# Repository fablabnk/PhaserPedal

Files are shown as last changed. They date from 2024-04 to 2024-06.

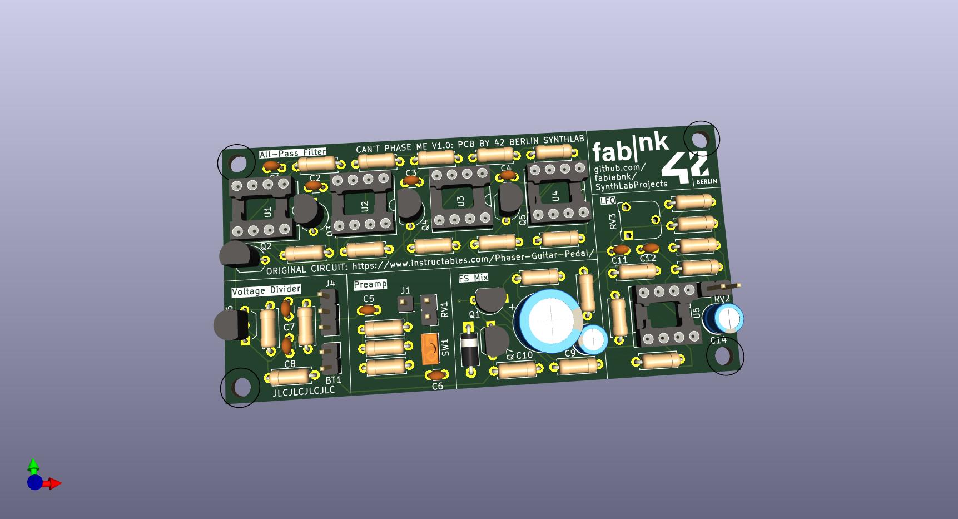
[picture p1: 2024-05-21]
3dPedal.jpg

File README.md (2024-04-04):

This was a project to build a [Phaser Guitar Pedal from Instructables](https://www.instructables.com/Phaser-Guitar-Pedal/). 

As we attempted the project, we found that the build steps in the photos were incomplete, so it is actually impossible to place all components and make all the solder connections on the protoboard in the same way they did.

Our solution was to attempt to rework a new layout directly from the schematic in KiCad, partly as a learning experience in how to use KiCad at all. This involved:

- recreating the schematic in the schematic editor
- creating a board template in the pcb editor and placing components as similarly as possible to the original project
- routing the rats nest
- using the routings as a template for soldering

- some connections are done with solder bridges, some with wires - the wires are the traces - but how did we do solder bridges again?

The current state of the project is that the circuit doesn't work and we're not sure why. One wire got disconnected so this could help.

A possible next step could be to manufacture a PCB, but we have no guarantee that we routed it correctly or that the project even works in the first place.

So it would be better to go back to first principles to understand the concepts in the circuit

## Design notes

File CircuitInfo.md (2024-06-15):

# V1.1

Aims:
- get it working with original BOM

Tasks:
- DONE: get schematic to pass ERC check
- mount to the case using tape etc. Case spec: HA29830PSLA: 120x95x34mm
- Audio In, Audio Out, 2 x pots, Footswitch and 9V battery will all be point-to-point wired
- DONE: use DPDT footswitch instead of SPST: it's the only footswitch we have
    - when closed, clean signal only makes it to output. when open, phased signal allowed through to be mixed with clean signal
    - we will wire only one pole and one throw of the DPDT, the other will remain disconnected
    - we presume pin 2 is connected to pin 1 when switch is in up position (clean) so will wire our phaser to pin 3 (wet)
- optimise component placement
- does jack wiring make sense? tip to ground etc?
- route it using ground plane - does power plane make sense?

# Lasercut Layout Test Notes

inline transistor footprints would have been fine!
we have no:     
    - 43K resistor:  33K + 10K
    - 3.9K resistor: 3.3K + 68
    - 39K resistor: 33K + 5.1K
    - 510K resistor: 470K + 47K (or use chunky brown one)
    - we have 510, 390, and 130's in brown chunky type
154s are too small, need to use a longer footprint 0.9mm between
*OR* ignore magical capacitors as they are not used in instructables!

# Workflow

- rework the schematic - modular with labels - more clarity
- simulate the circuit so we can test the different stages
     - preamp
     - all-pass
     - LFO
     - foot switch
- eliminate weird resistor values from circuit
- decide on PCB size
- layout PCB according to 5 sections
- route ground plane (back)
- route signal plane (front)
- send for manufacture

# Understanding the Circuit

5 x LM741 - op amps
4 x 2N5457 FET transistors
3 x 2N3904 transistor

1. Input
    - Guitar preamp
    - 1 x 2N3904 transistor
    - Clean signal to output jack
    - Clean signal to phasers shifter

2. Phaser Shifter
    - AKA an all-pass filter
    - consists of 4x LM741 op amps
    - shifts the phase based on signal from the LFO

3. LFO 
    - outputs a CV to the all-pass filter
    - consists of an LM741 op-amp, 50K pot and 4 x 2N5457 transistors

4. Output
    - Output of phaser shifter goes to foot switch
    - When switch is open only the clean signal passes through to output
    - When switch is closed the phase shifted signal passes through a 50K pot, which determines how much of it is mixed with the clean signal
    - what is purpose of trimpot?

5. Power    
    - drops voltage from 9V battery: first to 7V then 4V (using 2 x 2N3904 transistors)
    - 7V goes to guitar preamp transistor
    - 5V goes to all-pass filter 4 x 2N5457 transistors, then to LM741's

# PCB Size

mount points

#

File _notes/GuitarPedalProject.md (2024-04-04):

# Guitar Pedal Schematic Research

Bottom line: we need to convert the schematic to some other form, either breadboard, stripboard or PCB

## Breadboard

- Advantage is we can test and troubleshoot the circuit
- Disadvantage is breadboarding introduces problems of its own
- We still need to do a CAD layout of the schematic as the circuit is too complex to do directly on the breadboard

## Stripboard

- Two options 1. breadboard -> stripboard, 2. straight to stripboard
- What kind of stripboard? The one where we have to connect tracks or the one where we have to break tracks?
- Either way we design the layout in CAD software
- If we do 1. we should order or create breadboard-like stripboard, so as not to have to redo the layout.
- If creating, we should use the type where we break tracks

## PCB

We could skip breadboarding and stripboarding and go straight to manufacturing a single PCB. The circuit is already tried and tested, so main points of failure would be 1. human error translating the layout and 2. differences in components. In this case we should simulate as far as possible with SPICE software

What would it cost?

## SPICE simulation

Do we need to simulate the circuit at all?

## KiCad

The steps we should take are?

1. Replicate the guitar pedal schematic in KiCad itself

2. Lay it out as a either as a stripboard layout or PCB

Q: is there a dark-mode for the schematic editor?

https://github.com/pointhi/kicad-color-schemes

### Can KiCad do SPICE simulation?

KiCad supports netlist export, which allows you to export your circuit schematics in a format compatible with various SPICE simulation tools. You can then import this netlist into a separate SPICE simulator for simulation purposes.

Popular SPICE simulators that can be used in conjunction with KiCad include:

ngspice: This is an open-source SPICE simulator that is frequently used with KiCad. It's available for multiple operating systems.

LTspice: While not open-source, LTspice is a free SPICE simulator provided by Analog Devices. Many engineers use LTspice alongside KiCad for circuit simulation.

QUCS (Quite Universal Circuit Simulator): Although not strictly a SPICE simulator, QUCS is another option for simulating electronic circuits and can work in conjunction with KiCad.

### Confusion in the schematic

Q: in the hand drawn schematic i have some connections going to the negative terminal of a 9v battery and some going to a ground symbol. are these basically the same? What do they do in the stripboard circuit we can see?

Q: bottom right there are green tracks that cross, are they connected?

Q: do connections to audio jack go to tip?

Q: why do some black connections go first through the audio jack to get to negative rail of battery? Are these TRS

Q: some black connections cross, coming from 100K resistor to audio jack

To check
- that I got the pinouts of the transistors right
- results from electrical rules checker
- check that it's okay not to have some op amp chip pins connected

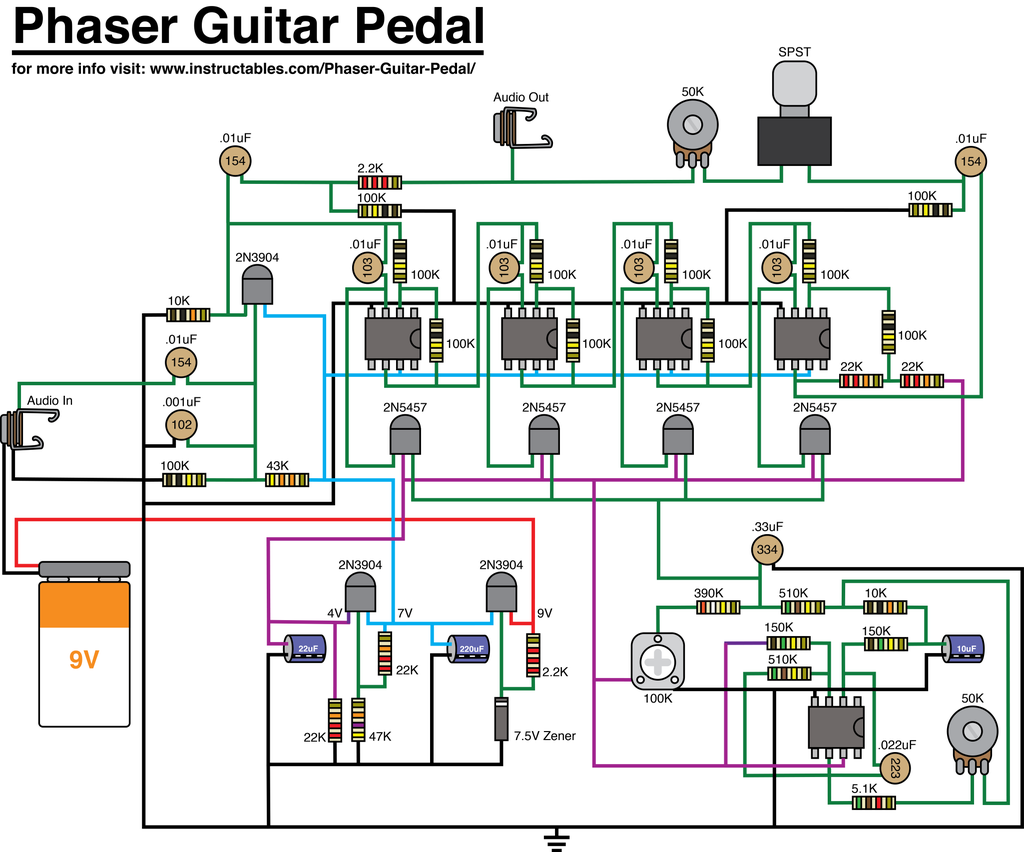
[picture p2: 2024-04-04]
schematic.webp

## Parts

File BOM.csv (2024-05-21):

Id | Designator | Footprint | Quantity | Designation | Supplier and ref
1 | SW1 | PinHeader_1x02_P2.54mm_Vertical | 1 | SW_SPST
2 | J1 | PinHeader_1x02_P2.54mm_Vertical | 1 | Audio Out
3 | D1 | D_A-405_P7.62mm_Horizontal | 1 | D_Zener 7.5V
4 | Q7,Q1,Q6 | TO-92_Inline_Wide | 3 | 2N3904
5 | R21,R24 | R_Axial_DIN0207_L6.3mm_D2.5mm_P7.62mm_Horizontal | 2 | 510K
6 | R22,R14 | R_Axial_DIN0207_L6.3mm_D2.5mm_P7.62mm_Horizontal | 2 | 10K
7 | U1,U5,U4,U2,U3 | DIP-8_W7.62mm_Socket | 5 | LM741
8 | Q2,Q4,Q5,Q3 | TO-92_Inline_Wide | 4 | 2N5457 (JFET)
9 | R15,R9,R4,R8,R11,R3,R1,R7,R6,R5,R10 | R_Axial_DIN0207_L6.3mm_D2.5mm_P7.62mm_Horizontal | 11 | 100K
10 | C12 | C_Disc_D3.0mm_W1.6mm_P2.50mm | 1 | 223
11 | R25,R23 | R_Axial_DIN0207_L6.3mm_D2.5mm_P7.62mm_Horizontal | 2 | 150K
12 | C10 | CP_Radial_D10.0mm_P5.00mm | 1 | 220µF
13 | C1,C2,C4,C3 | C_Disc_D3.0mm_W1.6mm_P2.50mm | 4 | 103
14 | R18,R13,R16,R12 | R_Axial_DIN0207_L6.3mm_D2.5mm_P7.62mm_Horizontal | 4 | 22K
15 | RV3 | Potentiometer_Runtron_RM-065_Vertical | 1 | 100K
16 | RV2,RV1 | PinHeader_1x02_P2.54mm_Vertical | 2 | 50K
17 | C5,C7,C6 | C_Disc_D3.0mm_W1.6mm_P2.50mm | 3 | 154
18 | J4 | PinHeader_1x03_P2.54mm_Vertical | 1 | Audio In
19 | C11 | C_Disc_D3.0mm_W1.6mm_P2.50mm | 1 | 334
20 | R19,R2 | R_Axial_DIN0207_L6.3mm_D2.5mm_P7.62mm_Horizontal | 2 | 2.2K
21 | C8 | C_Disc_D3.0mm_W1.6mm_P2.50mm | 1 | 102
22 | R20 | R_Axial_DIN0207_L6.3mm_D2.5mm_P7.62mm_Horizontal | 1 | 390K
23 | R17 | R_Axial_DIN0207_L6.3mm_D2.5mm_P7.62mm_Horizontal | 1 | 47K
24 | C9 | CP_Radial_D5.0mm_P2.50mm | 1 | 22µF
25 | C14 | CP_Radial_D5.0mm_P2.50mm | 1 | 10µF
26 | R26 | R_Axial_DIN0207_L6.3mm_D2.5mm_P7.62mm_Horizontal | 1 | 5.1K
27 | R27 | R_Axial_DIN0207_L6.3mm_D2.5mm_P7.62mm_Horizontal | 1 | 43K
28 | BT1 | PinHeader_1x02_P2.54mm_Vertical | 1 | 9V

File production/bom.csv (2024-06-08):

Designator | Footprint | Quantity | Value | LCSC Part #
BT1 | PinHeader_1x02_P2.54mm_Vertical | 1 | 9V Battery
C1, C2, C3, C4 | C_Axial_L5.1mm_D3.1mm_P7.50mm_Horizontal | 4 | 103
C10 | CP_Radial_D10.0mm_P5.00mm | 1 | 220µF
C11 | C_Disc_D3.0mm_W1.6mm_P2.50mm | 1 | 334
C12 | C_Axial_L5.1mm_D3.1mm_P7.50mm_Horizontal | 1 | 223
C14 | CP_Radial_D5.0mm_P2.50mm | 1 | 10µF
C5, C6, C7 | C_Disc_D3.0mm_W1.6mm_P2.50mm | 3 | 154
C8 | C_Axial_L5.1mm_D3.1mm_P7.50mm_Horizontal | 1 | 102
C9 | CP_Radial_D5.0mm_P2.50mm | 1 | 22µF
D1 | D_A-405_P7.62mm_Horizontal | 1 | Z7.5V
J1 | PinHeader_1x02_P2.54mm_Vertical_TR | 1 | AudioJack3
J2 | PinHeader_1x03_P2.54mm_Vertical_TRS | 1 | AudioJack3
Q1, Q6, Q7 | TO-92_Inline_Wide | 3 | 2N3904
Q2, Q3, Q4, Q5 | TO-92_Inline_Wide | 4 | 2N5457
R1, R10, R11, R15, R3, R4, R5, R6, R7, R8, R9 | R_Axial_DIN0204_L3.6mm_D1.6mm_P5.08mm_Horizontal | 11 | 100K
R12, R13, R16, R18 | R_Axial_DIN0204_L3.6mm_D1.6mm_P5.08mm_Horizontal | 4 | 22K
R14, R22 | R_Axial_DIN0204_L3.6mm_D1.6mm_P5.08mm_Horizontal | 2 | 10K
R17 | R_Axial_DIN0204_L3.6mm_D1.6mm_P5.08mm_Horizontal | 1 | 47K
R19, R2 | R_Axial_DIN0204_L3.6mm_D1.6mm_P5.08mm_Horizontal | 2 | 2.2K
R20 | R_Axial_DIN0204_L3.6mm_D1.6mm_P5.08mm_Horizontal | 1 | 330K
R21 | R_Axial_DIN0204_L3.6mm_D1.6mm_P5.08mm_Horizontal | 1 | 470K
R23, R25 | R_Axial_DIN0204_L3.6mm_D1.6mm_P5.08mm_Horizontal | 2 | 150K
R24 | R_Axial_DIN0204_L3.6mm_D1.6mm_P5.08mm_Horizontal | 1 | 510K
R26 | R_Axial_DIN0204_L3.6mm_D1.6mm_P5.08mm_Horizontal | 1 | 5.1K
R27 | R_Axial_DIN0204_L3.6mm_D1.6mm_P5.08mm_Horizontal | 1 | 43K
R28 | R_Axial_DIN0204_L3.6mm_D1.6mm_P5.08mm_Horizontal | 1 | 56K
R29 | R_Axial_DIN0204_L3.6mm_D1.6mm_P5.08mm_Horizontal | 1 | 3.9K
R30 | R_Axial_DIN0204_L3.6mm_D1.6mm_P5.08mm_Horizontal | 1 | 39K
R31 | R_Axial_DIN0204_L3.6mm_D1.6mm_P5.08mm_Horizontal | 1 | 1K
RV1, RV2 | PinHeader_1x02_P2.54mm_Vertical | 2 | 50K
RV3 | Potentiometer_Bourns_3296Y_Vertical | 1 | 100K
SW2 | PinHeader_1x02_P2.54mm_Vertical_2_3 | 1 | SW_DPDT_x2
U1, U2, U3, U4, U5 | DIP-8_W7.62mm_Socket | 5 | LM741

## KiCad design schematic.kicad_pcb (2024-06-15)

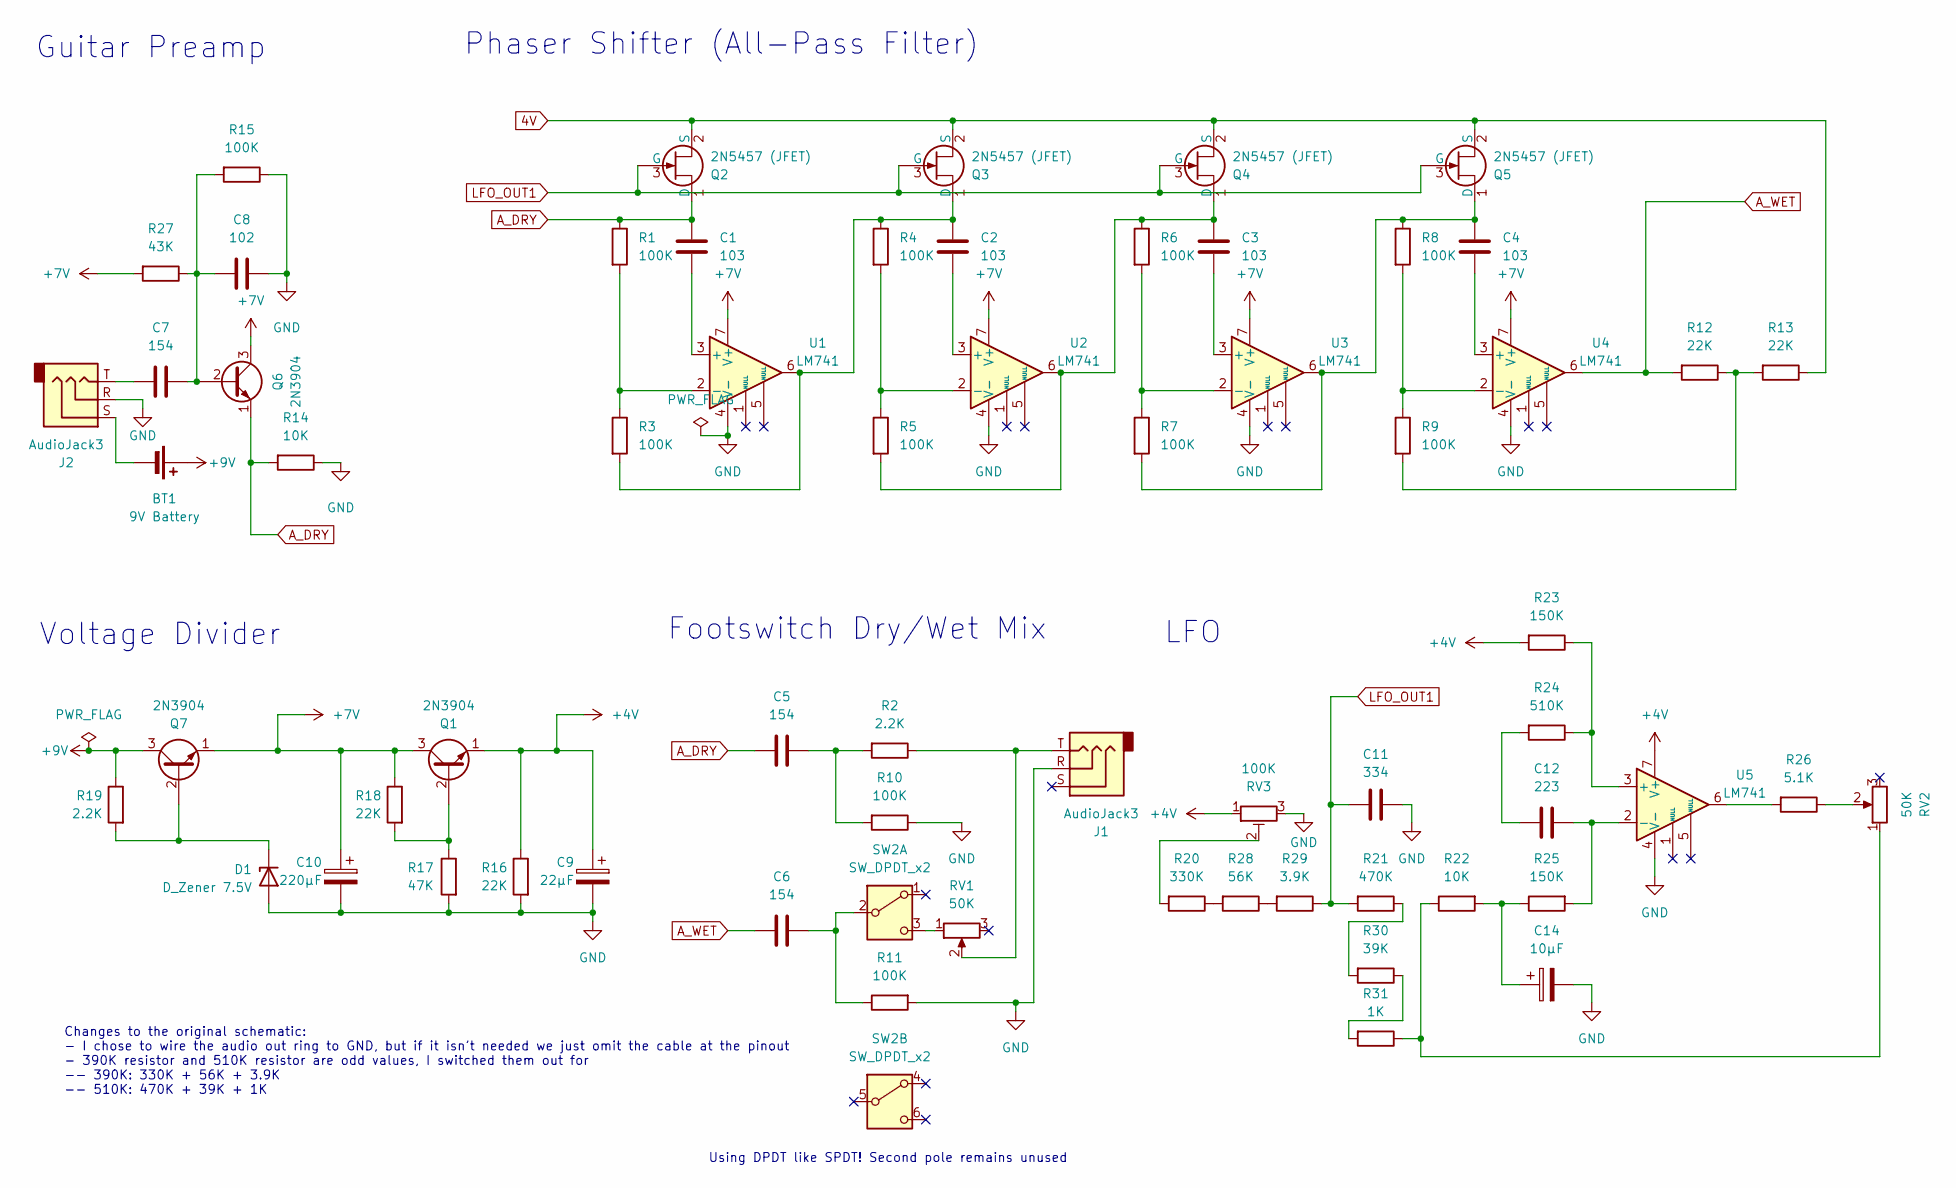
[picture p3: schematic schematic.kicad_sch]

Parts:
BT1: 9V Battery; PinHeader_1x02_P2.54mm_Vertical
C1, C2, C3, C4: 103; C_Axial_L5.1mm_D3.1mm_P7.50mm_Horizontal
C5, C6, C7: 154; C_Disc_D3.0mm_W1.6mm_P2.50mm
C8: 102; C_Axial_L5.1mm_D3.1mm_P7.50mm_Horizontal
C9: 22µF; CP_Radial_D5.0mm_P2.50mm
C10: 220µF; CP_Radial_D10.0mm_P5.00mm
C11: 334; C_Disc_D3.0mm_W1.6mm_P2.50mm
C12: 223; C_Axial_L5.1mm_D3.1mm_P7.50mm_Horizontal
C14: 10µF; CP_Radial_D5.0mm_P2.50mm
D1: D_Zener 7.5V; D_A-405_P7.62mm_Horizontal
J1: AudioJack3; PinHeader_1x02_P2.54mm_Vertical_TR
J2: AudioJack3; PinHeader_1x03_P2.54mm_Vertical_TRS
Q1, Q6, Q7: 2N3904; TO-92_Inline_Wide
Q2, Q3, Q4, Q5: 2N5457 (JFET); TO-92_Inline_Wide
R1, R3, R4, R5, R6, R7, R8, R9, R10, R11, R15: 100K; R_Axial_DIN0204_L3.6mm_D1.6mm_P5.08mm_Horizontal
R2, R19: 2.2K; R_Axial_DIN0204_L3.6mm_D1.6mm_P5.08mm_Horizontal
R12, R13, R16, R18: 22K; R_Axial_DIN0204_L3.6mm_D1.6mm_P5.08mm_Horizontal
R14, R22: 10K; R_Axial_DIN0204_L3.6mm_D1.6mm_P5.08mm_Horizontal
R17: 47K; R_Axial_DIN0204_L3.6mm_D1.6mm_P5.08mm_Horizontal
R20: 330K; R_Axial_DIN0204_L3.6mm_D1.6mm_P5.08mm_Horizontal
R21: 470K; R_Axial_DIN0204_L3.6mm_D1.6mm_P5.08mm_Horizontal
R23, R25: 150K; R_Axial_DIN0204_L3.6mm_D1.6mm_P5.08mm_Horizontal
R24: 510K; R_Axial_DIN0204_L3.6mm_D1.6mm_P5.08mm_Horizontal
R26: 5.1K; R_Axial_DIN0204_L3.6mm_D1.6mm_P5.08mm_Horizontal
R27: 43K; R_Axial_DIN0204_L3.6mm_D1.6mm_P5.08mm_Horizontal
R28: 56K; R_Axial_DIN0204_L3.6mm_D1.6mm_P5.08mm_Horizontal
R29: 3.9K; R_Axial_DIN0204_L3.6mm_D1.6mm_P5.08mm_Horizontal
R30: 39K; R_Axial_DIN0204_L3.6mm_D1.6mm_P5.08mm_Horizontal
R31: 1K; R_Axial_DIN0204_L3.6mm_D1.6mm_P5.08mm_Horizontal
RV1, RV2: 50K; PinHeader_1x02_P2.54mm_Vertical
RV3: 100K; Potentiometer_Bourns_3296Y_Vertical
SW2: SW_DPDT_x2; PinHeader_1x02_P2.54mm_Vertical_2_3
U1, U2, U3, U4, U5: LM741; DIP-8_W7.62mm_Socket

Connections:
4V: Q2.2 (S), Q3.2 (S), Q4.2 (S), Q5.2 (S), R13.1
+4V: C9.1, Q1.1 (E), R16.1, R23.2, RV3.1, U5.7 (V+)
+7V: C10.1, Q1.3 (C), Q6.3 (C), Q7.1 (E), R18.1, R27.2, U1.7 (V+), U2.7 (V+), U3.7 (V+), U4.7 (V+)
+9V: BT1.1 (+), Q7.3 (C), R19.1
A_DRY: C1.1, C5.2, Q2.1 (D), Q6.1 (E), R1.1, R14.2
A_WET: C6.1, R12.2, U4.6
GND: C8.1, C9.2, C10.2, C11.1, C14.2, D1.2 (A), J1.R, J2.R, R10.1, R11.2, R14.1, R15.1, R16.2, R17.2, RV3.3, U1.4 (V-), U2.4 (V-), U3.4 (V-), U4.4 (V-), U5.4 (V-)
LFO_OUT1: C11.2, Q2.3 (G), Q3.3 (G), Q4.3 (G), Q5.3 (G), R21.2, R29.1
unnamed: BT1.2 (-), J2.S
unnamed: C5.1, R2.2, R10.2
unnamed: C7.2, J2.T
unnamed: C12.2, R24.2
unnamed: C14.1, R22.2, R25.1
unnamed: D1.1 (K), Q7.2 (B), R19.2
unnamed: J1.T, R2.1, RV1.2
unnamed: Q1.2 (B), R17.1, R18.2
unnamed: C2.1, Q3.1 (D), R3.2, R4.1, U1.6
unnamed: C3.1, Q4.1 (D), R5.2, R6.1, U2.6
unnamed: C4.1, Q5.1 (D), R7.2, R8.1, U3.6
unnamed: C7.1, C8.2, Q6.2 (B), R15.2, R27.1
unnamed: R9.2, R12.1, R13.2
unnamed: R20.1, R28.2
unnamed: R20.2, RV3.2
unnamed: R21.1, R30.2
unnamed: R22.1, R31.1, RV2.1
unnamed: R26.1, RV2.2
unnamed: R26.2, U5.6
unnamed: R28.1, R29.2
unnamed: R30.1, R31.2
unnamed: C6.2, R11.1, SW2.2 (B)
unnamed: RV1.1, SW2.3 (C)
unnamed: C1.2, U1.3 (+)
unnamed: R1.2, R3.1, U1.2 (-)
unnamed: C2.2, U2.3 (+)
unnamed: R4.2, R5.1, U2.2 (-)
unnamed: C3.2, U3.3 (+)
unnamed: R6.2, R7.1, U3.2 (-)
unnamed: C4.2, U4.3 (+)
unnamed: R8.2, R9.1, U4.2 (-)
unnamed: R23.1, R24.1, U5.3 (+)
unnamed: C12.1, R25.2, U5.2 (-)

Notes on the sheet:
Using DPDT like SPDT! Second pole remains unused
Footswitch Dry/Wet Mix
Voltage Divider
Phaser Shifter (All-Pass Filter)
Guitar Preamp
LFO
Changes to the original schematic: - I chose to wire the audio out ring to GND, but if it isn't needed we just omit the cable at the pinout - 390K resistor and 510K resistor are odd values, I switched them out for -- 390K: 330K + 56K + 3.9K -- 510K: 470K + 39K + 1K

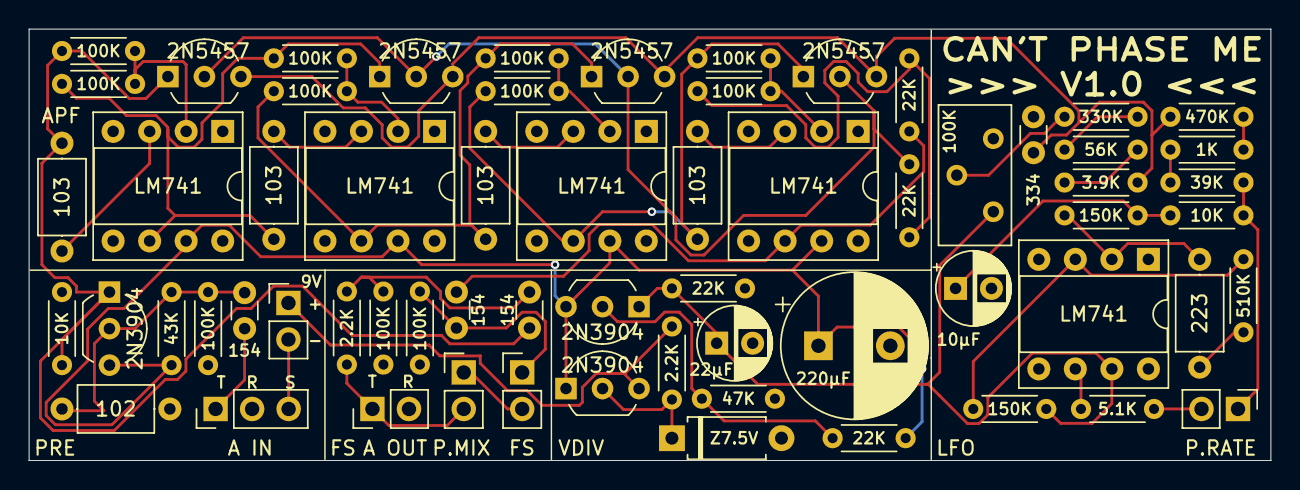
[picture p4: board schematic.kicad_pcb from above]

Board: 2 copper layers, 86.4 x 30.0 mm, 64 parts (0 on the bottom side), 41 nets.

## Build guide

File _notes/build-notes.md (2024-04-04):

kicad 	18 x 25
real 	25 x 31

(x1) 0.33uF capacitor
(x3) 0.15uF capacitors 250V154K	
(x1) 0.022uF capacitor MPP223J630V 		
(x4) 0.01uF capacitors 103K630V			10nF / 0.01uF 
(x1) 0.001uF capacitor 2A102J 			4.83nF / 0.00483

The brown resistors are measuring far less than their value!! Maybe we can't trust them

The Zener diode needs flipping to be vertical

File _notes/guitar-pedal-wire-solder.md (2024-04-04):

R13 is miswired!!
RV2 is not there - so neither are solder bridges to wires

- wire to right above Q4 i just soldered directly down instead of diagonal
- wire from centre of D1 i just soldered directly right instead of diagonal

battery terminals still need solder bridges

diagonal connection between R18 and R19 isn't done (with solder or wire?)

1
2
3
4
5
6
7
8
9
10
11
12
13
14

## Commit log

2024-06-08 smaller redesign - ready to test laser cut
    [bom.csv, designators.csv, positions.csv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]
2024-06-08 added notes to CircuitInfo.md after laser cutteer test - also deleted duplicate unfinished project files
    [lasercut.kicad_pcb, lasercut2.kicad_pcb, lasercut3.kicad_pcb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]
2024-06-15 pcb design now meets custom board rules for jlcpcb
    [schematic.kicad_pcb]
